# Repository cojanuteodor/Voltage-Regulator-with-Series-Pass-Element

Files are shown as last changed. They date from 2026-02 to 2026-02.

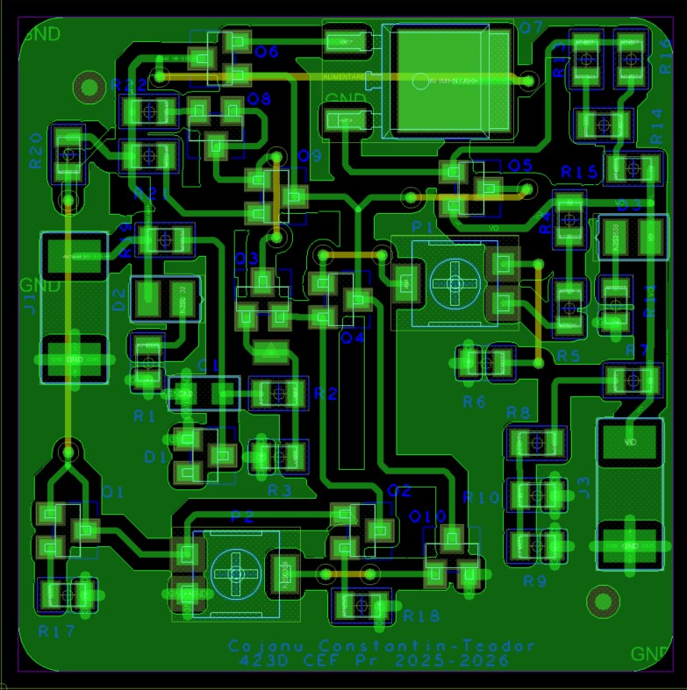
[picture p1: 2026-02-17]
Layout/Z_Z_LAYOUT.jpg

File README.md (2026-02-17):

# Voltage Regulator with Series Pass Element

## Specifications
- Adjustable output voltage: 2.5 V – 5 V  
- Input voltage range: 9 V – 10 V  
- Load resistance: 250 Ω  
- Maximum output current: 0.4 A (current limiting)  
- Thermal protection: series pass transistor limited to 100 °C  
- Thermal drift: < 2 mV/°C  
- Operating temperature range: 0 °C to 70 °C  
- Minimum open-loop voltage gain of error amplifier: ≥ 200  
- LED indicators for input and output voltage presence  

## Design Overview
The regulator is based on a linear series pass topology, where the output voltage is controlled by an error amplifier that compares a reference voltage with a feedback fraction of the output voltage. The series pass transistor operates in the linear region to regulate the output voltage under varying load and input conditions.

Main functional blocks:
- Reference voltage generator  
- Error amplifier (high open-loop gain)  
- Series pass element (BJT or MOSFET in SMD package)  
- Current limiting and thermal protection circuit  
- LED indicators for Vin and Vout  

## Implementation
- Technology: SMT & PCB  
- PCB size: 40 mm × 40 mm  
- Substrate: FR4, double-layer  
- Components: SMD 0805 passives, SMD transistors (SOT-23 / DPAK)  
- CAD Tools: OrCAD Capture & PCB Editor (Lite)  
- Simulation: PSPICE  

## Project Files
- Schematic and simulation files (PSPICE)  
- PCB layout (TOP/BOTTOM layers, solder mask, silk screen, mechanical layer)  
- Gerber files (RS-274X) and Excellon drill file  
- Bill of Materials (BOM)  
- Design documentation and calculations  

## Testing and Validation
The circuit was verified through:
- DC operating point analysis  
- Load regulation and line regulation simulations  
- Thermal behavior analysis of the series pass transistor  
- Functional testing of current limiting and thermal protection  
- Verification of output voltage range for N = 5  

## Notes
- All passive components use standard values and SMD 0805 packages.  
- Semiconductor devices are selected from standard catalogs.  
- The PCB layout follows IPC standards (IPC-2221A, IPC-7527, IPC-A-610).

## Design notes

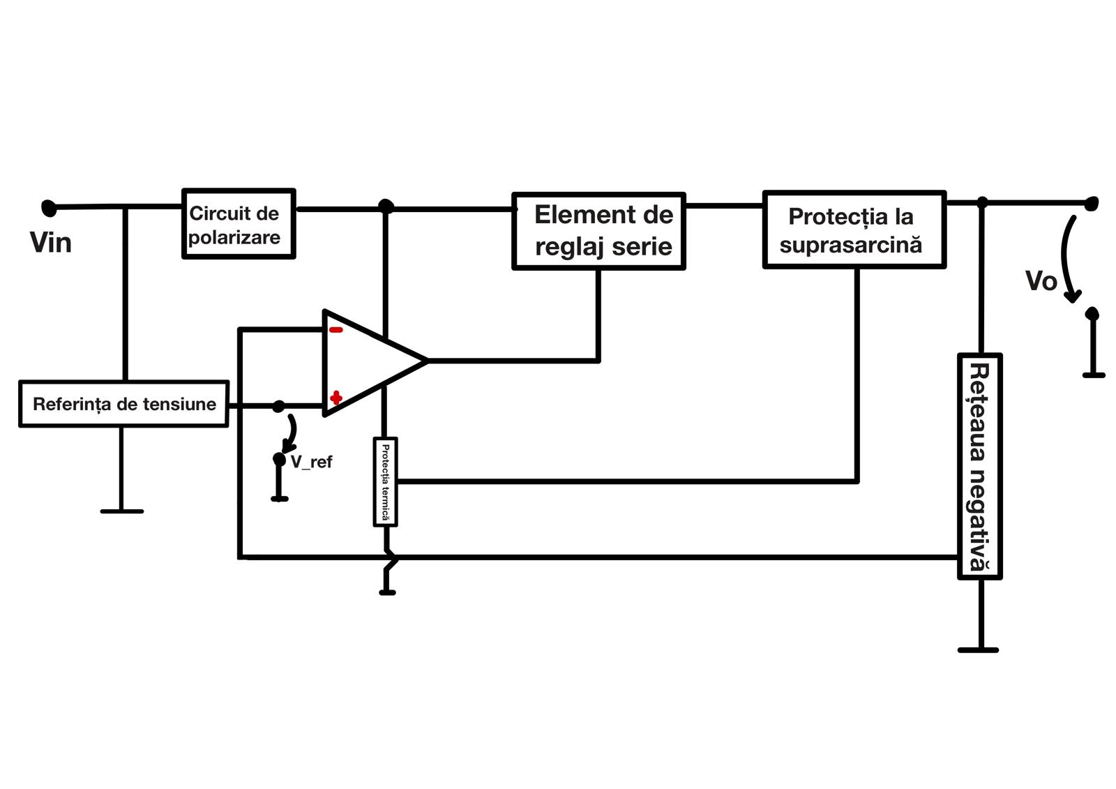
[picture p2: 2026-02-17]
schema_bloc.jpeg

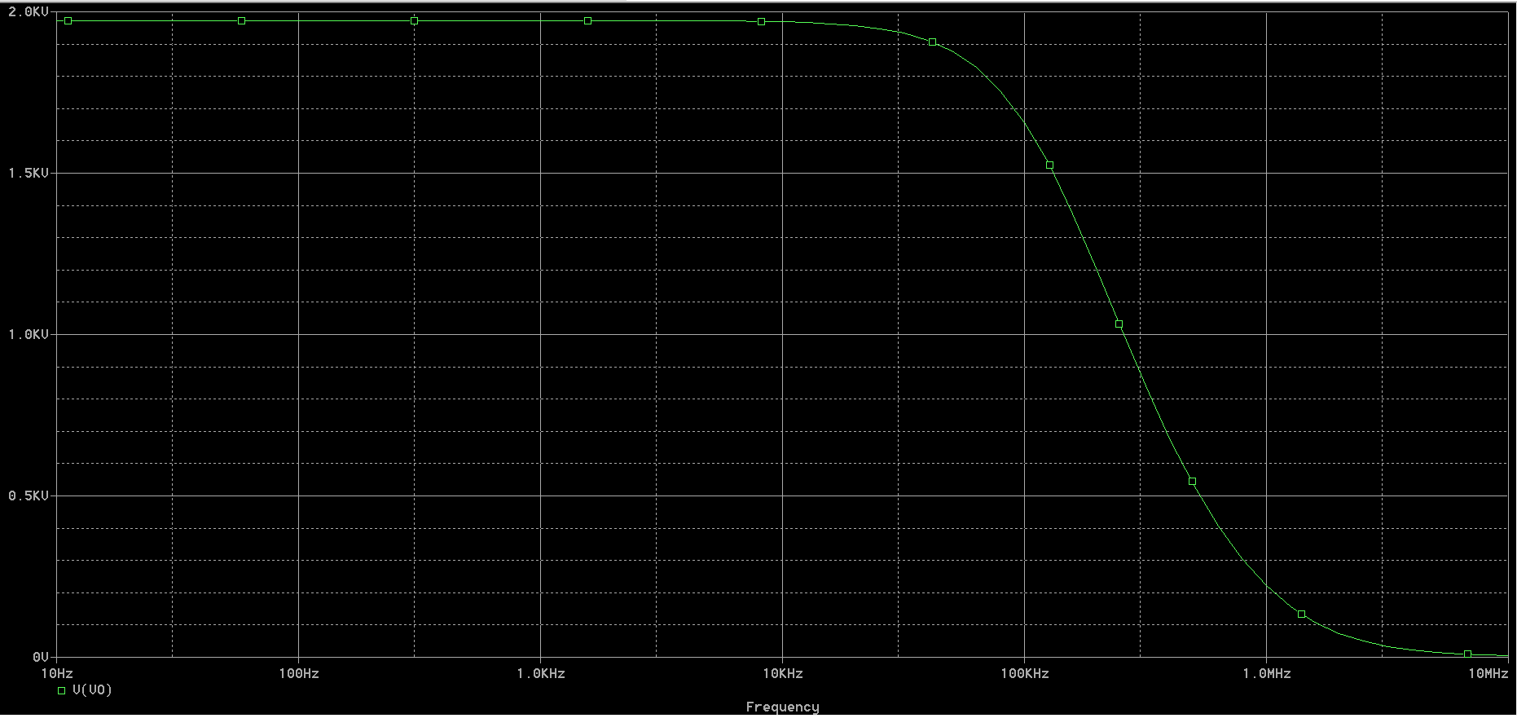
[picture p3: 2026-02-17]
Simulations/AMPLIFICARE_IN_BUCLA_DESCHISA.png

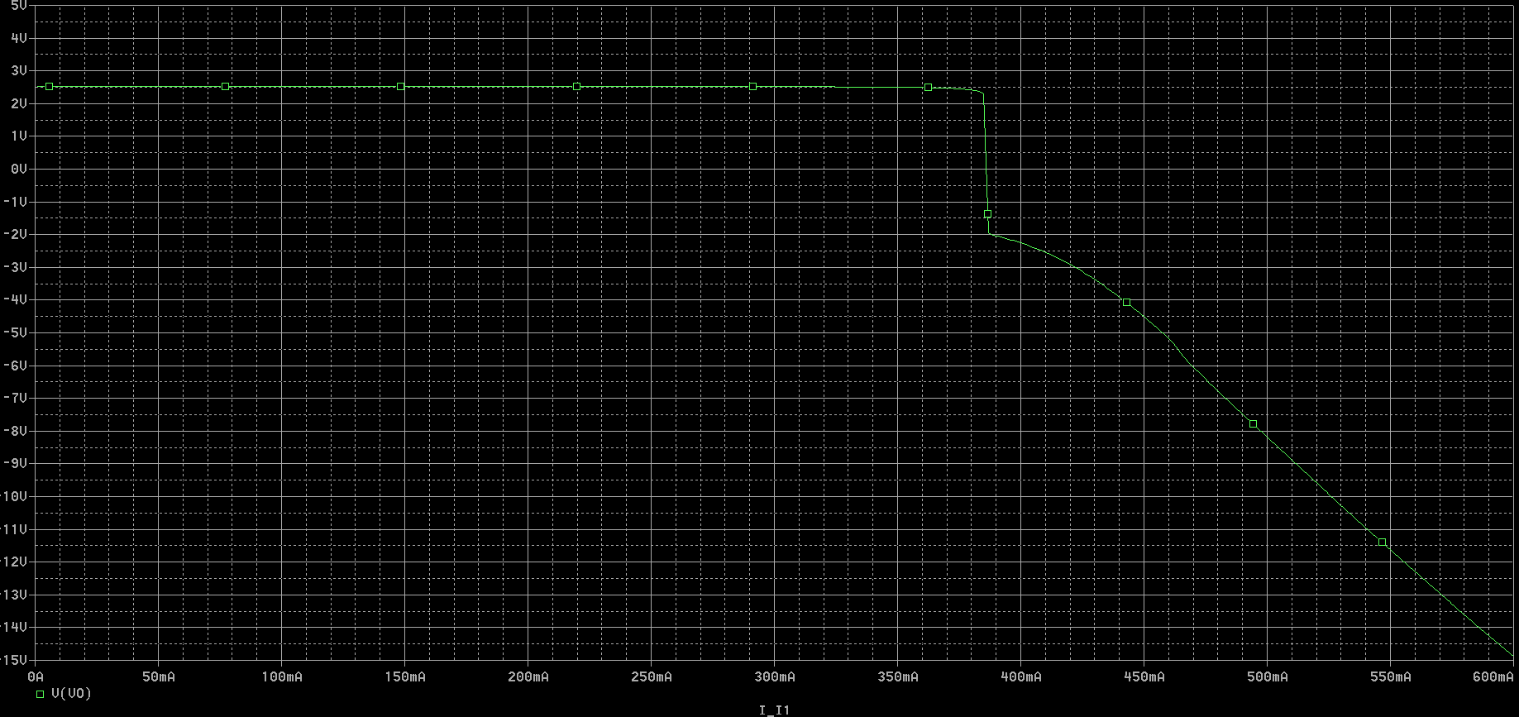
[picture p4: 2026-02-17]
Simulations/PROTECTIA_LA_SUPRASARCINA_VO_MIN.png

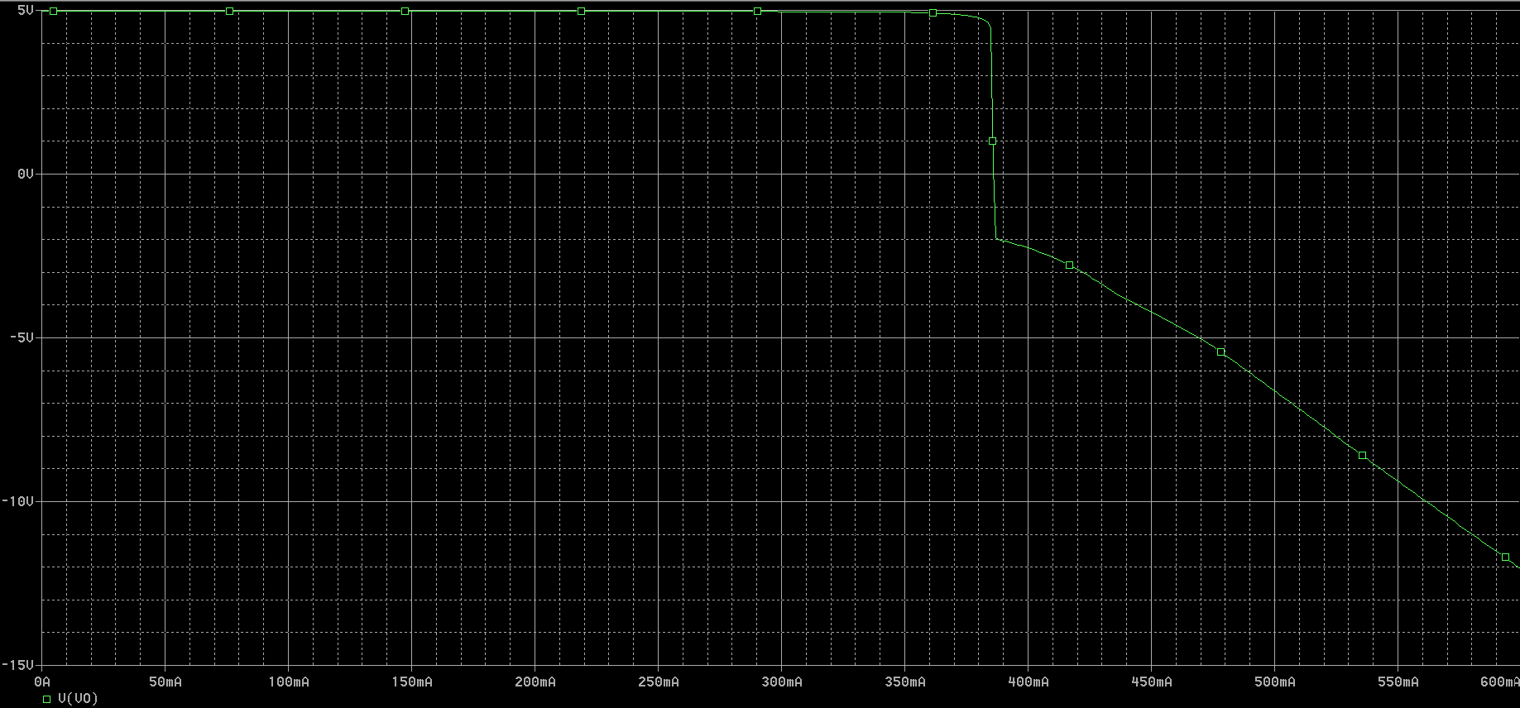
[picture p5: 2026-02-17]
Simulations/PROTECTIA_LA_SUPPRASARCINA_VO_MAX.png

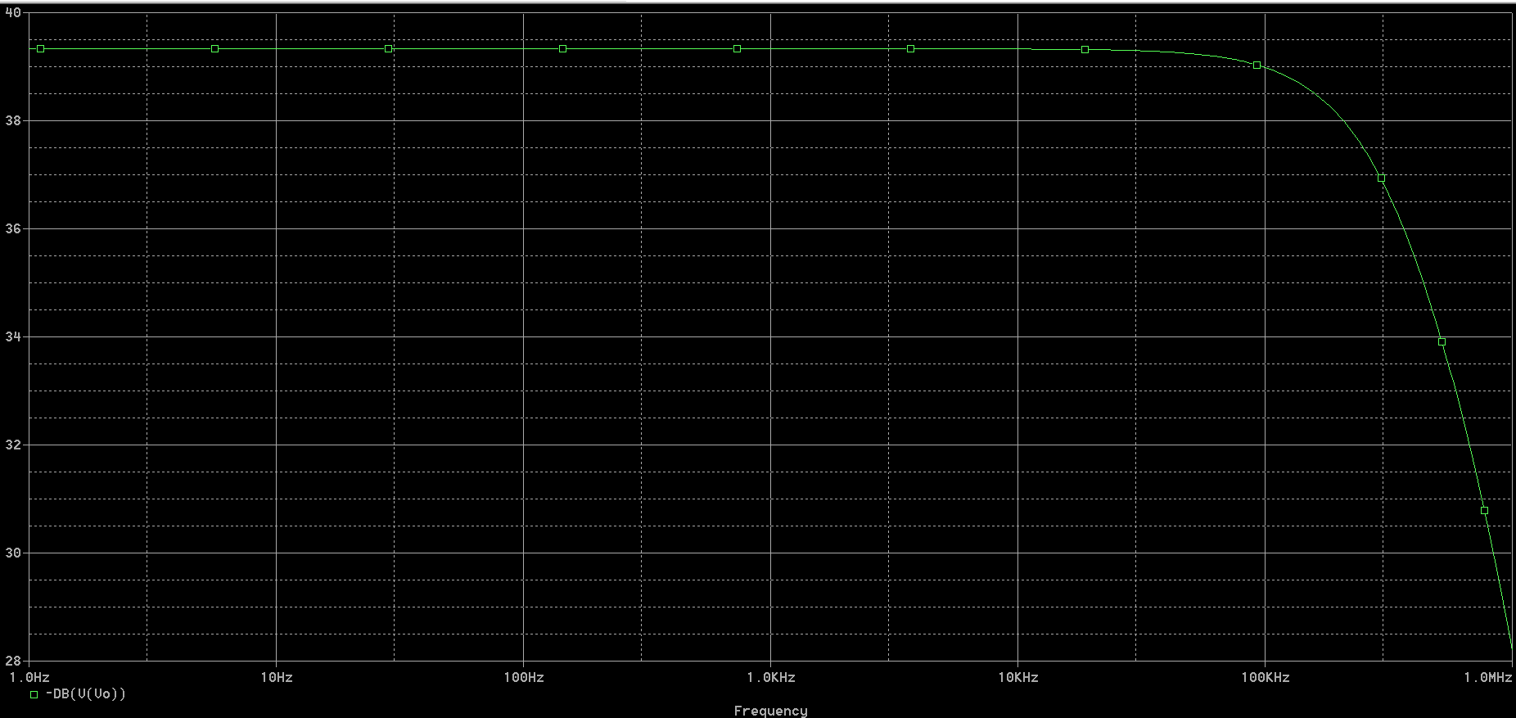
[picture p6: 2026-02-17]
Simulations/PSRR.png

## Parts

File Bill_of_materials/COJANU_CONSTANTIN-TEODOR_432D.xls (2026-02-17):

Anexa a1 - Grupa 432D - Tema 7 - Stabilizator de tensiune cu ERS
Nr. Crt. | Nume | Catalog | Cod distrib | Nume prod | Prod | Clasă | Qty fix | Qty final | Qty min | Descriere | Distribuitor | Pret (fara TVA) referinta/buc. TME România | Pret total pe reper (fara TVA) - propus
1 | 0 ohm | (LINK) (http://www.tme.eu/ro/details/smd1206-0r/rezistente-smd-1206/royal-ohm/1206s4j0000t5e/) | 1206S4J0000T5E | 1206S4J0000T5E | SR PASSIVES | rezistor | 0 |  |  | Rezistor: thick film; SMD; 1206; 0Ω; 0,25W; ±5%; -55÷125°C | TME România | 0.03841 | 0
2 | 0.47 | (LINK) (http://www.tme.eu/ro/details/smd0805-0r47/rezistente-smd-0805/royal-ohm/0805s8j047kt5e/) | SMD0805-0R47 | 0805S8J047KT5E | ROYAL OHM | rezistor | 20 |  |  | Rezistor SMD, chip, 0805, 0.47Ω, ±5%, 0.125W | TME România | 0.01454 | 0.2908
3 | 1 | (LINK) (https://www.tme.eu/ro/details/smd0805-1r/rezistente-smd-0805/royal-ohm/0805s8j010jt5e/) | SMD0805-1R-5% | 0805S8J010JT5E | ROYAL OHM | rezistor | 20 |  | 4 | Rezistor SMD, chip, 0805, 1Ω, ±5%, 0.125W | TME România | 0.01723 | 0.3446
4 | 4.7 | (LINK) (https://www.tme.eu/ro/details/smd0805-4r7/rezistente-smd-0805/royal-ohm/0805s8j047jt5e/) | SMD0805-4R7-5% | 0805S8J047JT5E | ROYAL OHM | rezistor | 10 |  |  | Rezistor SMD, chip, 0805, 4.7Ω, ±5%, 0.125W | TME România | 0.01723 | 0.1723
5 | 10 | (LINK) (https://www.tme.eu/ro/details/smd0805-10r/rezistente-smd-0805/royal-ohm/0805s8j0100t5e/) | SMD0805-10R-5% | 0805S8J0100T5E | ROYAL OHM | rezistor | 10 |  |  | Rezistor SMD, chip, 0805, 10Ω, ±5%, 0.125W | TME România | 0.01723 | 0.1723
6 | 22 | (LINK) (https://www.tme.eu/ro/details/smd0805-22r-1%25/rezistente-smd-0805/royal-ohm/0805s8f220jt5e/) | SMD0805-22R-1% | 0805S8F220JT5E | ROYAL OHM | rezistor | 20 |  |  | Rezistor SMD, chip, 0805, 22Ω, ±1%, 0.125W | TME România | 0.02127 | 0.4254
7 | 33 | (LINK) (https://www.tme.eu/ro/details/smd0805-33r/rezistente-smd-0805/royal-ohm/0805s8j0330t5e/) | SMD0805-33R-5% | 0805S8J0330T5E | ROYAL OHM | rezistor | 20 |  |  | Rezistor SMD, chip, 0805, 33Ω, ±5%, 0.125W | TME România | 0.01723 | 0.3446
8 | 51 | (LINK) (http://www.tme.eu/ro/details/rc0805jr-0751r/rezistente-smd-0805/yageo/rc0805jr-0751rl/) | SMD0805-51R-5% | 0805S8J0510T5E | ROYAL OHM | rezistor | 40 |  |  | Rezistor SMD, chip, 0805, 51Ω, ±5%, 0.125W | TME România | 0.0261 | 1.044
9 | 68 | (LINK) (http://www.tme.eu/ro/details/smd0805-68r-1%25/rezistente-smd-0805/royal-ohm/0805s8f680jt5e/) | SMD0805-68R-1% | 0805S8F680JT5E | ROYAL OHM | rezistor | 10 |  |  | Rezistor SMD, chip, 0805, 68Ω, ±1%, 0.125W | TME România | 0.04662 | 0.4662
10 | 82 | (LINK) (https://www.tme.eu/ro/details/wf08p-82r-5%25/rezistente-smd-0805/walsin/wf08p820jtl/) | SMD0805-82R-5% | WF08P820JTL | WALSIN | rezistor | 20 |  |  | Rezistor SMD, chip, 0805, 82Ω, ±5%, 0.125W | TME România | 0.0172 | 0.344
11 | 100 | (LINK) (https://www.tme.eu/ro/details/smd0805-100r/rezistente-smd-0805/royal-ohm/0805s8j0101t5e/) | SMD0805-100R-5% | 0805S8J0101T5E | ROYAL OHM | rezistor | 60 |  | 6 | Rezistor SMD, chip, 0805, 100Ω, ±5%, 0.125W | TME România | 0.01723 | 1.0338
12 | 150 | (LINK) (https://www.tme.eu/ro/details/smd0805-150r/rezistente-smd-0805/royal-ohm/0805s8j0151t5e/) | SMD0805-150R-5% | 0805S8F1500T5E | ROYAL OHM | rezistor | 30 |  |  | Rezistor SMD, chip, 0805, 150Ω, ±5%, 0.125W | TME România | 0.01723 | 0.5169
13 | 220 | (LINK) (http://www.tme.eu/ro/details/smd0805-220r-1%25/rezistente-smd-0805/royal-ohm/0805s8f2200t5e/) | SMD0805-220R-5% | 0805S8J0221T5E | ROYAL OHM | rezistor | 30 |  | 3 | Rezistor SMD, chip, 0805, 220Ω, ±5%, 0.125W | TME România | 0.02127 | 0.6381
14 | 330 | (LINK) (https://www.tme.eu/ro/details/smd0805-330r/rezistente-smd-0805/royal-ohm/0805s8j0331t5e/) | SMD0805-330R-5% | 0805S8J0331T5E | ROYAL OHM | rezistor | 30 |  |  | Rezistor SMD, chip, 0805, 330Ω, ±5%, 0.125W | TME România | 0.01723 | 0.5169
15 | 470 | (LINK) (https://www.tme.eu/ro/details/smd0805-470r/rezistente-smd-0805/royal-ohm/0805s8j0471t5e/) | SMD0805-470R-5% | 0805S8J0471T5E | ROYAL OHM | rezistor | 30 |  |  | Rezistor SMD, chip, 0805, 470Ω, ±5%, 0.125W | TME România | 0.01723 | 0.5169
16 | 510 | (LINK) (https://www.tme.eu/ro/details/smd0805-510r/rezistente-smd-0805/royal-ohm/0805s8j0511t5e/) | SMD0805-510R-5% | 0805S8J0511T5E | YAGEO | rezistor | 30 |  |  | Rezistor SMD, chip, 0805, 510Ω, ±5%, 0.125W | TME România | 0.01723 | 0.5169
17 | 680 | (LINK) (https://www.tme.eu/ro/details/smd0805-680r/rezistente-smd-0805/royal-ohm/0805s8j0681t5e/) | SMD0805-680R-5% | 0805S8J0681T5E | ROYAL OHM | rezistor | 30 |  | 1 | Rezistor SMD, chip, 0805, 680Ω, ±5%, 0.125W | TME România | 0.01723 | 0.5169
18 | 820 | (LINK) (https://www.tme.eu/ro/details/smd0805-820r/rezistente-smd-0805/royal-ohm/0805s8j0821t5e/) | SMD0805-820R-5% | 0805S8J0821T5E | ROYAL OHM | rezistor | 30 |  |  | Rezistor SMD, chip, 0805, 820Ω, ±5%, 0.125W | TME România | 0.01723 | 0.5169
19 | 910 | (LINK) (https://www.tme.eu/ro/details/rc0805jr-07910r/rezistente-smd-0805/yageo/rc0805jr-07910rl/) | SMD0805-910R-5% | RC0805JR-07910RL | YAGEO | rezistor | 40 |  |  | Rezistor SMD, chip, 0805, 910Ω, ±5%, 0.125W | TME România | 0.0261 | 1.044
20 | 1k | (LINK) (https://www.tme.eu/ro/details/smd0805-1k/rezistente-smd-0805/royal-ohm/0805s8j0102t5e/) | SMD0805-1K-5% | 0805S8J0102T5E | ROYAL OHM | rezistor | 100 |  | 2 | Rezistor SMD, chip, 0805, 1kΩ, ±5%, 0.125W | TME România | 0.01723 | 1.723
21 | 1.5k | (LINK) (https://www.tme.eu/ro/details/wf08p-1k5-5%25/rezistente-smd-0805/walsin/wf08p152jtl/) | SMD0805-1K5-5% | WF08P152JTL | WALSIN | rezistor | 40 |  |  | Rezistor SMD, chip, 0805, 1.5kΩ, ±5%, 0.125W | TME România | 0.0172 | 0.688
22 | 1.8k | (LINK) (https://www.tme.eu/ro/details/smd0805-1k8/rezistente-smd-0805/royal-ohm/0805s8j0182t5e/) | SMD0805-1K8-5% | 0805S8J0182T5E | ROYAL OHM | rezistor | 30 |  |  | Rezistor SMD, chip, 0805, 1.8kΩ, ±5%, 0.125W | TME România | 0.01723 | 0.5169
23 | 2k | (LINK) (https://www.tme.eu/ro/details/smd0805-2k/rezistente-smd-0805/royal-ohm/0805s8j0202t5e/) | SMD0805-2K-5% | 0805S8J0202T5E | ROYAL OHM | rezistor | 80 |  |  | Rezistor SMD, chip, 0805, 2kΩ, ±5%, 0.125W | TME România | 0.01723 | 1.3784
24 | 2.2k | (LINK) (https://www.tme.eu/ro/details/smd0805-2k2/rezistente-smd-0805/royal-ohm/0805s8j0222t5e/) | SMD0805-2K2-5% | 0805S8J0222T5E | ROYAL OHM | rezistor | 30 |  |  | Rezistor SMD, chip, 0805, 2.2kΩ, ±5%, 0.125W | TME România | 0.01723 | 0.5169
25 | 2.7k | (LINK) (https://www.tme.eu/ro/details/smd0805-2k7/rezistente-smd-0805/royal-ohm/0805s8j0272t5e/) | SMD0805-2K7-5% | 0805S8F2701T5E | ROYAL OHM | rezistor | 30 |  |  | Rezistor SMD, chip, 0805, 2.7kΩ, ±5%, 0.125W | TME România | 0.01723 | 0.5169
26 | 3.3k | (LINK) (https://www.tme.eu/ro/details/smd0805-3k3/rezistente-smd-0805/royal-ohm/0805s8j0332t5e/) | SMD0805-3K3-5% | 0805S8J0332T5E | ROYAL OHM | rezistor | 20 |  | 2 | Rezistor SMD, chip, 0805, 3.3kΩ, ±5%, 0.125W | TME România | 0.01723 | 0.3446
27 | 3.9k | (LINK) (https://www.tme.eu/ro/details/smd0805-3k9/rezistente-smd-0805/royal-ohm/0805s8j0392t5e/) | SMD0805-3K9-5% | 0805S8J0392T5E | ROYAL OHM | rezistor | 20 |  | 1 | Rezistor SMD, chip, 0805, 3.9kΩ, ±5%, 0.125W | TME România | 0.01723 | 0.3446
28 | 4.7k | (LINK) (https://www.tme.eu/ro/details/smd0805-4k7/rezistente-smd-0805/royal-ohm/0805s8j0472t5e/) | SMD0805-4K7-5% | 0805S8J0472T5E | ROYAL OHM | rezistor | 30 |  |  | Rezistor SMD, chip, 0805, 4.7kΩ, ±5%, 0.125W | TME România | 0.01723 | 0.5169
29 | 5.6k | (LINK) (https://www.tme.eu/ro/details/smd0805-5k6/rezistente-smd-0805/royal-ohm/0805s8j0562t5e/) | SMD0805-5K6-5% | 0805S8J0562T5E | ROYAL OHM | rezistor | 40 |  | 2 | Rezistor SMD, chip, 0805, 5.6kΩ, ±5%, 0.125W | TME România | 0.01723 | 0.6892
30 | 6.8k | (LINK) (https://www.tme.eu/ro/details/rc0805jr-076k8/rezistente-smd-0805/yageo/rc0805jr-076k8l/) | SMD0805-6K8-5% | RC0805JR-076K8L | YAGEO | rezistor | 20 |  |  | Rezistor SMD, chip, 0805, 6.8kΩ, ±5%, 0.125W | TME România | 0.0261 | 0.522
31 | 8.2k | (LINK) (https://www.tme.eu/ro/details/smd0805-8k2/rezistente-smd/royalohm/0805s8j0822t5e/) | SMD0805-8K2-5% | 0805S8J0822T5E | ROYAL OHM | rezistor | 30 |  |  | Rezistor SMD, chip, 0805, 8.2kΩ, ±5%, 0.125W | TME România | 0.01723 | 0.5169
32 | 9.1k | (LINK) (https://www.tme.eu/ro/details/smd0805-9k1/rezistente-smd-0805/royal-ohm/0805s8j0912t5e/) | SMD0805-9K1-5% | 0805S8J0912T5E | ROYAL OHM | rezistor | 20 |  |  | Rezistor SMD, chip, 0805, 9.1kΩ, ±5%, 0.125W | TME România | 0.01723 | 0.3446
33 | 10k | (LINK) (https://www.tme.eu/ro/details/smd0805-10k/rezistente-smd-0805/royal-ohm/0805s8j0103t5e/) | SMD0805-10K-5% | 0805S8J0103T5E | ROYAL OHM | rezistor | 100 |  |  | Rezistor SMD, chip, 0805, 10kΩ, ±5%, 0.125W | TME România | 0.01723 | 1.723
34 | 15k | (LINK) (https://www.tme.eu/ro/details/smd0805-15k/rezistente-smd-0805/royal-ohm/0805s8j0153t5e/) | SMD0805-15K-5% | 0805S8J0153T5E | ROYAL OHM | rezistor | 30 |  |  | Rezistor SMD, chip, 0805, 15kΩ, ±5%, 0.125W | TME România | 0.01723 | 0.5169
35 | 22k | (LINK) (https://www.tme.eu/ro/details/smd0805-22k/rezistente-smd-0805/royal-ohm/0805s8j0223t5e/) | SMD0805-22K-5% | 0805S8J0223T5E | ROYAL OHM | rezistor | 30 |  |  | Rezistor SMD, chip, 0805, 22kΩ, ±5%, 0.125W | TME România | 0.01723 | 0.5169
36 | 47k | (LINK) (http://www.tme.eu/ro/details/smd0805-47k/rezistente-smd-0805/royal-ohm/0805s8j0473t5e/) | SMD0805-47K-5% | 0805S8J0473T5E | ROYAL OHM | rezistor | 40 |  |  | Rezistor: thick film; SMD; 0805; 47kΩ; 0,125W; ±5%; -55÷125°C | TME România | 0.01723 | 0.6892
37 | 68k | (LINK) (https://www.tme.eu/ro/details/smd0805-68k/rezistente-smd-0805/royal-ohm/0805s8j0683t5e/) | SMD0805-68K-5% | 0805S8J0683T5E | ROYAL OHM | rezistor | 20 |  |  | Rezistor SMD, chip, 0805, 68kΩ, ±5%, 0.125W | TME România | 0.01723 | 0.3446
38 | 100k | (LINK) (https://www.tme.eu/ro/details/smd0805-100k/rezistente-smd-0805/royal-ohm/0805s8j0104t5e/) | SMD0805-100K-5% | 0805S8J0104T5E | ROYAL OHM | rezistor | 100 |  |  | Rezistor SMD, chip, 0805, 100kΩ, ±5%, 0.125W | TME România | 0.01723 | 1.723
39 | 150k | (LINK) (http://www.tme.eu/ro/details/smd0805-150k/rezistente-smd-0805/royal-ohm/0805s8j0154t5e/) | SMD0805-150K-5% | 0805S8J0154T5E | ROYAL OHM | rezistor | 30 |  |  | Rezistor SMD, chip, 0805, 150kΩ, ±5%, 0.125W | TME România | 0.01723 | 0.5169
40 | 180k | (LINK) (http://www.tme.eu/ro/details/smd0805-180k/rezistente-smd-0805/royal-ohm/0805s8j0184t5e/) | SMD0805-180K-5% | 0805S8J0184T5E | ROYAL OHM | rezistor | 30 |  |  | Rezistor SMD, chip, 0805, 180kΩ, ±5%, 0.125W | TME România | 0.01723 | 0.5169
41 | 220k | (LINK) (https://www.tme.eu/ro/details/smd0805-220k/rezistente-smd-0805/royal-ohm/0805s8j0224t5e/) | SMD0805-220K-5% | 0805S8J0224T5E | ROYAL OHM | rezistor | 30 |  |  | Rezistor SMD, chip, 0805, 220kΩ, ±5%, 0.125W | TME România | 0.01723 | 0.5169
42 | 330k | (LINK) (https://www.tme.eu/ro/details/smd0805-330k/rezistente-smd-0805/royal-ohm/0805s8j0334t5e/) | SMD0805-330K-5% | 0805S8J0334T5E | ROYAL OHM | rezistor | 30 |  |  | Rezistor SMD, chip, 0805, 330kΩ, ±5%, 0.125W | TME România | 0.01723 | 0.5169
43 | 390k | (LINK) (https://www.tme.eu/ro/details/smd0805-390k/rezistente-smd-0805/royal-ohm/0805s8j0394t5e/) | SMD0805-390K-5% | 0805S8J0394T5E | ROYAL OHM | rezistor | 30 |  |  | Rezistor SMD, chip, 0805, 390kΩ, ±5%, 0.125W | TME România | 0.01723 | 0.5169
44 | 510k | (LINK) (https://www.tme.eu/ro/details/smd0805-510k/rezistente-smd-0805/royal-ohm/0805s8j0514t5e/) | SMD0805-510K-5% | 0805S8J0514T5E | ROYAL OHM | rezistor | 30 |  |  | Rezistor SMD, chip, 0805, 510kΩ, ±5%, 0.125W | TME România | 0.01723 | 0.5169
45 | 1M | (LINK) (https://www.tme.eu/ro/details/crcw08051m00jntabc/rezistente-smd-0805/vishay/) | SMD0805-1M-5% | CRCW08051M00JNTABC | VISHAY | rezistor | 0 |  |  | Rezistor SMD, chip, 0805, 1MΩ, ±5%, 0.125W | TME România | 0.01151 | 0
46 | 2M | (LINK) (http://www.tme.eu/ro/details/smd0805-2m/rezistente-smd-0805/royal-ohm/0805waj-2m-t5e/) | SMD0805-2M7 5% | 0805WAJ 2M T5E | ROYAL OHM | rezistor | 0 |  |  | Rezistor SMD, chip, 0805, 2MΩ, ±1%, 0.125W | TME România | 0.01723 | 0
47 | 5,1M | (LINK) (http://www.tme.eu/ro/details/smd0805-5m1/rezistente-smd-0805/royal-ohm/0805s8j0515t5e/) | SMD0805-5M1 5% | RC0805FR-075M1 | Yageo | rezistor | 0 |  |  | Rezistor SMD, chip, 0805, 5.1MΩ, ±1%, 0.125W | TME România | 0.01723 | 0
48 | 10M | (LINK) (https://www.tme.eu/ro/details/0805s8j0106t5e/rezistente-smd-0805/royal-ohm/) | SMD0805-10M 5% | 0805S8J0106T5E | ROYAL OHM | rezistor | 0 |  |  | Rezistor SMD, chip, 0805, 10MΩ, ±5%, 0.125W | TME România | 0.01723 | 0
49 | 100ohm | (LINK) (https://www.tme.eu/ro/details/ts53yl100r/trimere-smd-cu-o-singura-tura/vishay/ts53yl101mr10/) | 1804GSMD-100R | 1804GSMD-100R | SR PASSIVES | potențiometru | 15 |  |  | Potențiome-tru liniar, simplă tură, SMD, 100Ω, ±10%, 100ppm/°C, 0.25W | TME România | 3.77 | 56.55
50 | 500ohm | (LINK) (https://www.tme.eu/ro/details/ts53yl500r/trimere-smd-cu-o-singura-tura/vishay/ts53yl501mr10/) | 1804GSMD-500R | 1804GSMD-500R | VISHAY | potențiometru | 0 |  |  | Potențiome-tru liniar, simplă tură, SMD, 500Ω, ±10%, 100ppm/°C, 0.25W | TME România | 2.19 | 0
51 | 2k | (LINK) (https://www.tme.eu/ro/details/ts53yl2k/trimere-smd-cu-o-singura-tura/vishay/ts53yl202mr10/) | TS53YL202MR10 | TS53YL202MR10 | VISHAY | potențiometru | 0 |  |  | Potențiome-tru liniar, simplă tură, SMD, 2kΩ, ±20%, 100ppm/°C, 0.25W | TME România | 2.84 | 0
52 | 5k | (LINK) (http://www.tme.eu/ro/details/3314g-1-502e/trimere-smd-cu-o-singura-tura/bourns/) | 3314G-1-502E | 3314G-1-502E | BOURNS | potențiometru | 40 |  | 2 | Potențiome-tru liniar, simplă tură, SMD, 5kΩ, ±20%, 100ppm/°C, 0.25W | TME România | 3.45 | 138
53 | 10k | (LINK) (http://www.tme.eu/ro/details/3314g-1-103e/trimere-smd-cu-o-singura-tura/bourns/) | 3314G-1-103E | 3314G-1-103E | BOURNS | potențiometru | 20 |  |  | Potențiome-tru liniar, simplă tură, SMD, 10kΩ, ±20%, 100ppm/°C, 0.25W | TME România | 3.0573 | 61.146
54 | 50k | (LINK) (http://www.tme.eu/ro/details/3314g-1-503e/trimere-smd-cu-o-singura-tura/bourns/) | 3314G-1-503E | 3314G-1-503E | BOURNS | potențiometru | 0 |  |  | Potențiome-tru liniar, simplă tură, SMD, 50kΩ, ±20%, 100ppm/°C, 0.25W | TME România | 2.84 | 0
55 | 100k | (LINK) (http://www.tme.eu/ro/details/ts53yl100k/trimere-smd-cu-o-singura-tura/vishay/ts53yl104mr10/) | TS53YL104MR10 | TS53YL104MR10 | VISHAY | potențiometru | 10 |  |  | Potențiome-tru liniar, simplă tură, SMD, 100kΩ, ±20%, 100ppm/°C, 0.25W | TME România | 2.61 | 26.1
56 | 500k | (LINK) (http://www.tme.eu/ro/details/3314g-1-504e/trimere-smd-cu-o-singura-tura/bourns/) | 3314G-1-504E | 3314G-1-504E | BOURNS | potențiometru | 0 |  |  | Potențiome-tru liniar, simplă tură, SMD, 500kΩ, ±10%, 100ppm/°C, 0.25W | TME România | 2.8802 | 0
 | TOTAL - Componente pasive (rezistoare de valori fixe şi reglabile) |  |  |  |  |  |  |  |  | FARA TVA = | 308.4514 | CU TVA= | 382.479736
57 | 4.7pF | (LINK) (http://www.tme.eu/ro/details/cc0805crnpo94r7/condensatoare-mlcc-smd-0805/yageo/cc0805crnpo9bn4r7/) | CC0805CRNPO9BN4R7 | CC0805CRNPO9BN4R7 | YAGEO | condensator | 20 |  |  | ceramic; MLCC; 4,7pF; 50V; C0G; ±0,25pF; SMD; 0805 | TME România | 0.16643 | 3.3286
58 | 10pF | (LINK) (http://www.tme.eu/ro/details/cc0805jrnpo9100/condensatoare-mlcc-smd-0805/yageo/cc0805jrnpo9bn100/) | CC0805JRNPO9BN100 | CC0805JRNPO9BN100 | YAGEO | condensator | 20 |  |  | ceramic; MLCC; 10pF; 50V; C0G; ±5%; SMD; 0805 | TME România | 0.1649 | 3.298
59 | 47pF | (LINK) (http://www.tme.eu/ro/details/cl21c470jbannnc/condensatoare-mlcc-smd-0805/samsung/) | CL21C470JBANNNC | CL21C470JBANNNC | SAMSUNG | condensator | 20 |  |  | Condensator: ceramic; MLCC; 47pF; 50V; C0G; ±5%; SMD; 0805; -55÷125°C | TME România | 0.11097 | 2.2194
60 | 100pF | (LINK) (http://www.tme.eu/ro/details/cl21c101jbannnc/condensatoare-mlcc-smd-0805/samsung/) | CL21C101JBANNNC | CL21C101JBANNNC | SAMSUNG | condensator | 20 |  |  | Condensator: ceramic; MLCC; 100pF; 50V; C0G; ±5%; SMD; 0805 | TME România | 0.05427 | 1.0854
61 | 470pF | (LINK) (https://www.tme.eu/ro/details/c0805c471k5rac/condensatoare-mlcc-smd/kemet/c0805c471k5ractu/) | C0805C471K5RACTU | C0805C471K5RACTU | KEMET | condensator | 20 |  |  | Condensator: ceramic; MLCC; 470pF; 50V; X7R; ±10%; SMD; 0805 | TME România | 0.12123 | 2.4246
62 | 1nF | (LINK) (https://www.tme.eu/ro/details/cl21b102kbannnc/condensatoare-mlcc-smd/samsung/) | CL21B102KBANNNC | CL21B102KBANNNC | SAMSUNG | condensator | 0 |  |  | Condensator MLCC, SMD, 0805, 1nF, ±5%, 50V, C0G | TME România | 0.06487 | 0
63 | 2.2nF | (LINK) (https://www.tme.eu/ro/details/cl21b222jbannnc/condensatoare-mlcc-smd-0805/samsung/) | CL21B222JBANNNC | CL21B222JBANNNC | SAMSUNG | condensator | 0 |  |  | Condensator: ceramic; MLCC; 2,2nF; 50V; X7R; ±10%; SMD; 0805 | TME România | 0.1485 | 0
64 | 4.7nF | (LINK) (https://www.tme.eu/ro/details/cl21b472kbannnc/condensatoare-mlcc-smd-0805/samsung/) | CL21B472KBANNNC | CL21B472KBANNNC | SAMSUNG | condensator | 0 |  |  | Condensator MLCC, SMD, 0805, 4.7nF, ±5%, 50V, X7R | TME România | 0.08943 | 0
65 | 5.6nF | (LINK) (https://www.tme.eu/ro/details/cl21b562kbannnc/condensatoare-mlcc-smd-0805/samsung/) | CL21B562KBANNNC | CL21B562KBANNNC | SAMSUNG | condensator | 0 |  |  | Condensator MLCC, SMD, 0805, 5.6nF, ±5%, 50V, X7R | TME România | 0.04517 | 0
66 | 10nF | (LINK) (https://www.tme.eu/ro/details/cl21b103kbannnd/condensatoare-mlcc-smd-0805/samsung/) | CL21B103KBANNND | CL21B103KBANNND | SAMSUNG | condensator | 40 |  | 1 | Condensator MLCC, SMD, 0805, 10nF, ±5%, 50V, X7R | TME România | 0.06093 | 2.4372
67 | 22nF | (LINK) (http://www.tme.eu/ro/details/cl21b223kcfnnne/condensatoare-mlcc-smd-0805/samsung/) | CL21B223KBANNNC | CL21B223KBANNNC | SAMSUNG | condensator | 0 |  |  | Condensator: ceramic; MLCC; 22nF; 100V; X7R; ±10%; SMD; 0805 | TME România | 0.13823 | 0
68 | 33nF | (LINK) (https://www.tme.eu/ro/details/vj0805y333kxacw1bc/condensatoare-mlcc-smd-0805/vishay/) | VJ0805Y333KXACW1BC | VJ0805Y333KXACW1BC | VISHAY | condensator | 0 |  |  | Condensator: ceramic; MLCC; 33nF; 50V; X7R; ±10%; SMD; 0805 | TME România | 0.05417 | 0
69 | 100nF | (LINK) (https://www.tme.eu/ro/details/cl21b104kbcnnnc/condensatoare-mlcc-smd/samsung/) | CL21B104KBCNNNC | CL21B104KBCNNNC | SAMSUNG | condensator | 40 |  |  | ceramic; MLCC; 100nF; 50V; X7R; ±10%; SMD; 0805 | TME România | 0.3759 | 15.036
70 | 220nF | (LINK) (http://www.tme.eu/ro/details/cl21b224kafnnne/condensatoare-mlcc-smd-0805/samsung/) | CL21B224KAFNNNE | CL21B224KAFNNNE | SAMSUNG | condensator | 0 |  |  | Condensator: ceramic; MLCC; 220nF; 25V; X7R; ±10%; SMD; 0805 | TME România | 0.10247 | 0
71 | 330nF | (LINK) (https://www.tme.eu/ro/details/grm219r71h334ka88d/condensatoare-mlcc-smd-0805/murata/) | GRM219R71H334KA88D | GRM219R71H334KA88D | MURATA | condensator | 0 |  |  | Condensator: ceramic; MLCC; 330nF; 50V; X7R; ±10%; SMD; 0805 | TME România | 0.5972 | 0
72 | 470nF | (LINK) (https://www.tme.eu/ro/details/cc0805mry5v8474/condensatoare-mlcc-smd-0805/yageo/cc0805mry5v8bb474/) | CC0805MRY5V8474 | CC0805MRY5V8BB474 | YAGEO | condensator | 0 |  |  | Condensator: ceramic; MLCC; 470nF; 50V; Y5V; -20÷+80%; SMD; 0805 | TME România | 0.0758 | 0
73 | 1uF | (LINK) (https://www.tme.eu/ro/details/cl21b105kbfnnng/condensatoare-mlcc-smd-0805/samsung/) | CL21B105KBFNNNG | CL21B105KBFNNNG | SAMSUNG | condensator | 20 |  |  | Condensator: ceramic; MLCC; 1uF; 50V; X7R; ±20%; SMD; 0805 | TME România | 0.25253 | 5.0506
74 | 2.2uF | (LINK) (https://www.tme.eu/ro/details/grm21br61h225ka73l/condensatoare-mlcc-smd-0805/murata/) | GRM21BR61H225KA73L | GRM21BR61H225KA73L | MURATA | condensator | 20 |  |  | Condensator: ceramic; MLCC; 2,2uF; 25V; X5R; ±10%; SMD; 0805 | TME România | 0.4486 | 8.972
75 | 4.7uF | (LINK) (https://www.tme.eu/ro/details/cl21a475kaqnnng/condensatoare-mlcc-smd-0805/samsung/) | CL21A475KAQNNNG | CL21A475KAQNNNG | SAMSUNG | condensator | 20 |  |  | ceramic; MLCC; 4,7uF; 25V; X5R; ±10%; SMD; 0805 | TME România | 0.25373 | 5.0746
76 | 10uF | (LINK) (https://www.tme.eu/ro/details/eee1ha100sp/condensatoare-electrolitice-smd/panasonic/) | EEE1HA100SP | EEE1HA100SP | PANASONIC | condensator | 16 |  |  | Condensator: electrolitic; SMD; 10uF; 50V | TME România | 0.2284 | 3.6544
 | TOTAL - Componente pasive (condensatoare) |  |  |  |  |  |  |  |  | FARA TVA = | 52.5808 | CU TVA= | 65.200192
77 | 4148 | (LINK) (http://www.tme.eu/ro/details/1n4148-0805/diode-universale-smd/dc-components/cd4148ws0805c/) | 1N4148-0805 | CD4148WS(0805C) | DC Components | diodă pn | 40 |  |  | Diodă comutație, SMD, 0805, 300mA, 100V | TME România | 0.04555 | 1.822
78 | LED | (LINK) (https://www.tme.eu/ro/details/of-smd2012b/diode-led-smd-colorate/optoflash/) | OF-SMD2012B | OF-SMD2012B | OPTOFLASH | LED | 15 |  | 2 | LED albastru, SMD, 0805, 150-200mcd, 476nm, 120° | TME România | 0.1264 | 1.896
79 | 2.7V | (LINK) (https://www.tme.eu/ro/details/bzx84-c2v7.215/diode-zener-smd/nexperia/bzx84-c2v7-215/) | BZX84C2V7 | BZX84-C2V7LT1G | ON Semiconductor | diodă Zener | 5 |  | 1 | Diodă Zener, SMD, SOT23, 2,7V, ±5%, 0.25W | TME România | 0.05732 | 0.2866
80 | 5.1V | (LINK) (https://www.tme.eu/ro/details/bzx84-c5v1.215/diode-zener-smd/nexperia/) | BZX84C5V1 | BZX84-C5V1 | NEXPERIA | diodă Zener | 10 |  |  | Diodă Zener, SMD, SOT23, 5,1V, ±5%, 0.3W | TME România | 0.06245 | 0.6245
81 | 5.6V | (LINK) (https://www.tme.eu/ro/details/bzx84b5v6-dio/diode-zener-smd/diotec-semiconductor/bzx84b5v6/) | BZX84B5V6 | BZX84B5V6 | DIOTEC SEMICONDUCTOR | diodă Zener | 10 |  |  | Diodă Zener, SMD, SOT23, 5,6V, ±5%, 0.3W | TME România | 0.0839 | 0.839
82 | 6.2V | (LINK) (https://www.tme.eu/ro/details/bzx84-c6v2.215/diode-zener-smd/nexperia/) | BZX84C6V2 | BZX84-C6V2 | NEXPERIA | diodă Zener | 5 |  |  | Diodă Zener, SMD, SOT23, 6.2V, ±5%, 0.3W | TME România | 0.06618 | 0.3309
83 | 6.8V | (LINK) (https://www.tme.eu/ro/details/bzx84-c6v8.215/diode-zener-smd/nexperia/) | BZX84C6V8 | BZX84-C6V8 | NEXPERIA | diodă Zener | 0 |  |  | Diodă Zener, SMD, SOT23, 6.8V, ±5%, 0.3W | TME România | 0.05686 | 0
84 | 8.2V | (LINK) (https://www.tme.eu/ro/details/bzx84-c8v2.215/diode-zener-smd/nexperia/) | BZX84C8V2 | BZX84-C8V2 | NEXPERIA | diodă Zener | 5 |  |  | Diodă Zener, SMD, SOT23, 8.2V, ±5%, 0.3W | TME România | 0.05686 | 0.2843
85 | 10V | (LINK) (https://www.tme.eu/ro/details/bzx84-c10.215/diode-zener-smd/nexperia/) | BZX84C10 | BZX84-C10 | NEXPERIA | diodă Zener | 5 |  |  | Diodă Zener, SMD, SOT23, 10V, ±5%, 0.3W | TME România | 0.05686 | 0.2843
86 | PNP | (LINK) (http://www.tme.eu/ro/details/bc856b-dio/tranzistori-smd-pnp/diotec-semiconductor/bc856b/) | BC856B | BC856B | DIOTEC | tranzistor bipolar | 80 |  | 2 | Tranzistor bipolar PNP, SMD, SOT23, 80V, 100mA | TME România | 0.04055 | 3.244
87 | NPN | (LINK) (https://www.tme.eu/ro/details/bc846b-dio/tranzistori-smd-npn/diotec-semiconductor/bc846b/) | BC846B | BC846B | DIOTEC | tranzistor bipolar | 80 |  | 7 | Tranzistor bipolar NPN, SMD, SOT23, 65V, 100mA | TME România | 0.03379 | 2.7032
89 | N-JFET | (LINK) (http://www.tme.eu/ro/details/mmbfj309lt1g/tranzistori-canal-n-smd/on-semiconductor/) | MMBFJ309LT1G | MMBFJ309LT1G | ON Semiconductor | tranzistor NJFET | 40 |  |  | Tranzistor N-JFET, SMD, SOT23, 25V, 30mA | TME România | 0.8063 | 32.252
90 | P-JFET | (LINK) (http://www.tme.eu/ro/details/mmbfj177lt1g/tranzistori-canal-p-smd/on-semiconductor/) | MMBFJ177LT1G | MMBFJ177LT1G | ON Semiconductor | tranzistor PJFET | 15 |  |  | Tranzistor P-JFET, SMD, SOT23, 30V, 20mA | TME România | 0.8808 | 13.212
91 | NPN | (LINK) (http://www.tme.eu/ro/details/bc817-25-dio/tranzistori-smd-npn/diotec-semiconductor/bc817-25/) | BC817-25-DIO | BC817-25-DIO | NXP | tranzistor bipolar | 10 |  |  | Tranzistor bipolar NPN, SMD, SOT23, 45V, 800mA | TME România | 0.0494 | 0.494
93 | PNP | (LINK) (http://www.tme.eu/ro/details/bc807-25-dio/tranzistori-smd-pnp/diotec-semiconductor/bc807-25/) | BC807-25-DIO | BC807-25-DIO | NXP | tranzistor bipolar | 10 |  |  | Tranzistor bipolar PNP, SMD, SOT23, 45V, 800mA | TME România | 0.05406 | 0.5406
94 | NPN | (LINK) (http://www.tme.eu/ro/details/mjd31cg/tranzistori-smd-npn/on-semiconductor/) | MJD31CG | MJD31CG | ON Semiconductor | tranzistor bipolar | 20 |  | 1 | Tranzistor bipolar NPN, SMD, DPACK, 100V, 3A, 15W | TME România | 0.7037 | 14.074
96 | PNP | (LINK) (http://www.tme.eu/ro/details/mjd32cg/tranzistori-smd-pnp/on-semiconductor/) | MJD32CG | MJD32CG | ON Semiconductor | tranzistor bipolar | 20 |  |  | Tranzistor bipolar PNP, SMD, DPACK, 100V, 3A, 15W | TME România | 0.783 | 15.66
97 | Nmos | (LINK) (https://www.tme.eu/ro/details/irfr120ntrpbf/tranzistori-canal-n-smd/infineon-technologies/) | IRFR120NTRPBF | IRFR120NTRPBF | Infineon | tranzistor NMOS | 10 |  |  | Tranzistor N-MOSFET, SMD, DPAK, 100V, 9.1A, 20V, 39W | TME România | 1.03 | 10.3
 | TOTAL - Componente semiconductoare (tranzistoare bipolare şi cu efect de câmp, diode, LED, etc.) |  |  |  |  |  |  |  |  | FARA TVA = | 126.1474 | CU TVA= | 156.422776
98 | Conn2p | (LINK) (http://www.tme.eu/ro/details/zl301-40p/pini-cu-benzi-si-soclu/ninigi/) | ZL301-40P | ZL301-40P | NINIGI | Sir pini, pas 2,54mm, SMD | 0 |  |  | Sir pini, pas 2,54mm, SMD, tip tata, bareta de 40 pini | TME România | 2.3027 | 0
99 | FUSE | (LINK) (http://www.tme.eu/ro/details/3413.0116.11/sigurante-smd-1206-ultrarapide/schurter/) | 3413.0116.11 | 3413.0116.11 | SCHURTER | sigu-ranță | 0 |  |  | Siguranță sticlă, SMD, 1206, 1.25A, 48mΩ | TME România | 0 | 0
 | Total - Conectică, sigurante fuzibile, etc. |  |  |  |  |  |  |  |  | FARA TVA = | 0 | CU TVA= | 0
 | Total general |  |  |  |  |  |  |  |  | FARA TVA = | 487.1796 | CU TVA= | 579.743724

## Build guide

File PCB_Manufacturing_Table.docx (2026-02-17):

General info document for PCB manufacturing
No. | Item Name | File Name | | | | | | Info / Remarks / Notes
| BOARD
1 | Board Name / Number | ZSTABILIZATOR_FINAL.brd | | | | | | -
2 | Revision Date | 14 December 2025 | | | | | | -
3 | Board Size | 40 x 40 mm² | | | | | | -
4 | Board Quantity | 1 | | | | | | -
5 | Material / Dielectric Type | FR4 | | | | | | -
6 | Board Thickness | 1.6 mm | | | | | | -
7 | Copper Thickness | 18 μm | | | | | | -
| LAYERS
8 | Number of Electrical Layers | 2 | | | | | | -
9 | Copper Layer TOP | TOP.art | | | | | | -
10 | Copper Layer BOTTOM | BOT.art | | | | | | -
11 | Copper GND Plane | Included in TOP.art | | | | | | -
12 | Copper PWR Plane | - | | | | | | -
13 | Copper INNER 1 | - | | | | | | -
14 | Copper INNER 2 | - | | | | | | -
15 | Solder Mask TOP | SMTOP.art | | | | | | -
16 | Solder Mask BOTTOM | SMBOT.art | | | | | | -
17 | Solder Paste TOP | SPTOP.art | | | | | | -
18 | Solder Paste BOTTOM | - | | | | | | -
19 | Peelable Mask TOP | - | | | | | | -
20 | Peelable Mask BOTTOM | - | | | | | | -
21 | Silk Screen TOP | SSTOP.art | | | | | | -
22 | Silk Screen BOTTOM | - | | | | | | -
23 | Board Outline | BO.art | | | | | | -
24 | Fabrication Drawing | FAB.art | | | | | | -
| MILLING & DRILLING
25 | Mill Drawing | - | | | | | | -
26 | Drill Drawing | Included in FAB.art | | | | | | -
27 | N.C. Drill (for both PH & NPH) | DRILL.drl | | | | | | -
28 | N.C. Drill / Plated Holes (PH) | 14 | | | | | | -
29 | N.C. Drill / Non-Plated Holes (PH) | - | | | | | | -
| FINISHING
30 | Panelisation | - | | | | | | -
31 | Electrical Test | - | | | | | | -
32 | Copper Finishing | x | HASL | | OSP | | | ENIG
33 | Board Outline Machining | | Routing | | Milling | | x | V-Cutting
34 | Final remarks | - | | | | -

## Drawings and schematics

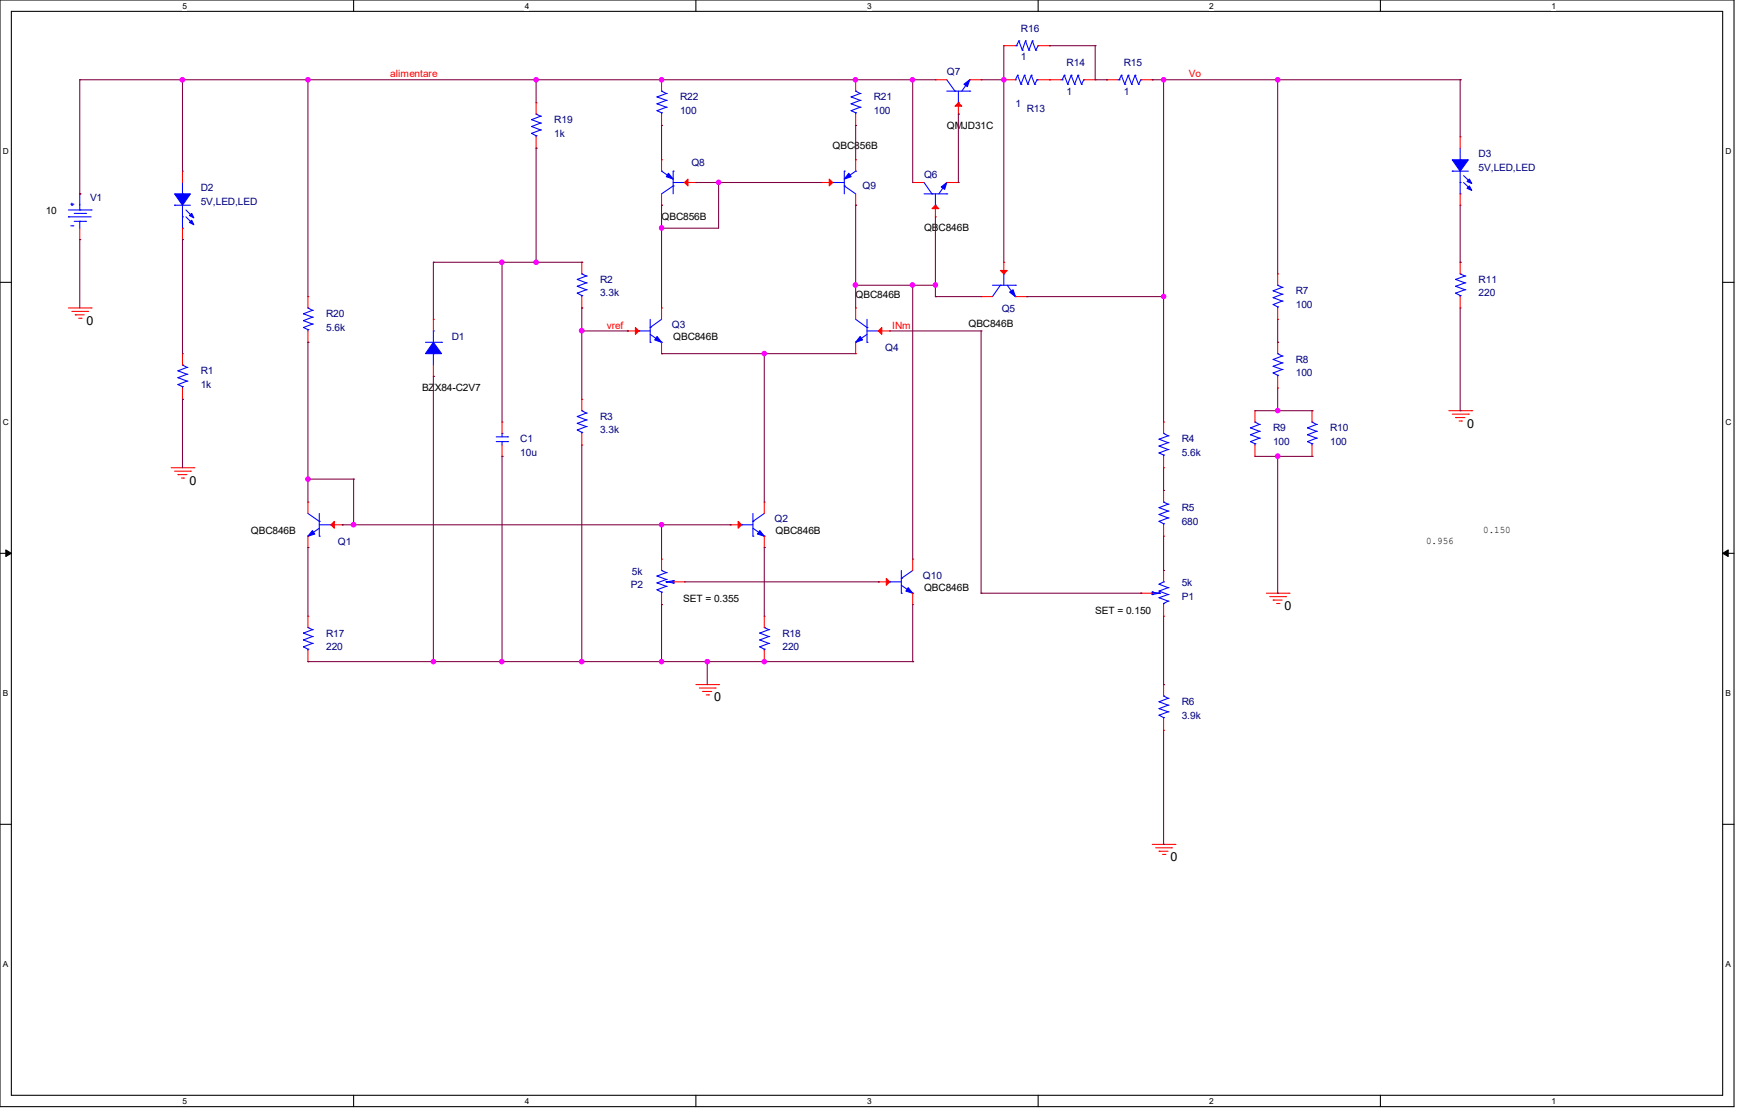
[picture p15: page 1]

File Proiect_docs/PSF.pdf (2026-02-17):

Calculate | punctulni static | de | functionate

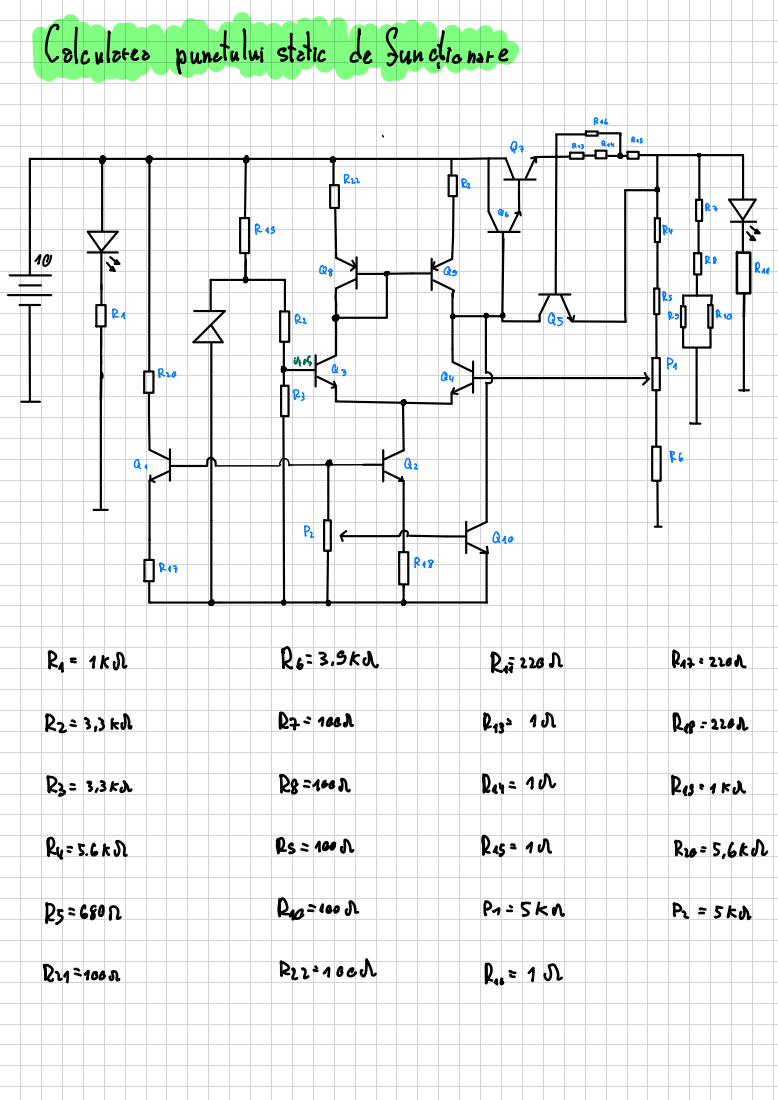
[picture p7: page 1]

& ↳ + | Qu-etaj | diferential Vinm =

# Vinp

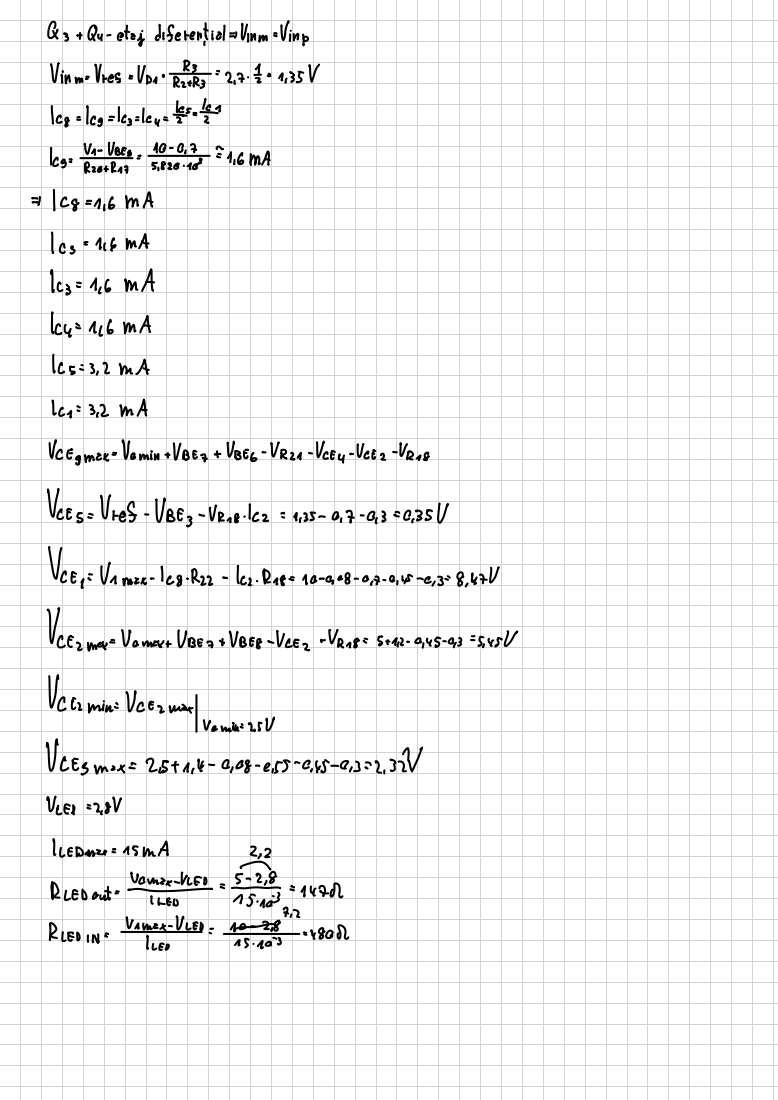
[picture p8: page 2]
Vinm= Vref; =Van R; \eg = 1cs = 1cuに; VUBEs1-EG ATA; InA; lcs; Ves = Vref-VBEy-VR18 /2; VCte = Unmax-1cg .; Res =; VCEnmer=; Vomer+ UBEz +; VBEO-VCEz; VaEz min:; VCEn max; Vomin: 2.5V; VCEsmax =; VCED; I LEDanze = 15 MA; RLEDout; Vemzx-ULED :; RLEDIN :; ILER; res

VCEgmax = Vamin +VBEz + VBEg-Vra1-Vcey-Vcez-VRes

# ↑uteri

# per resistente

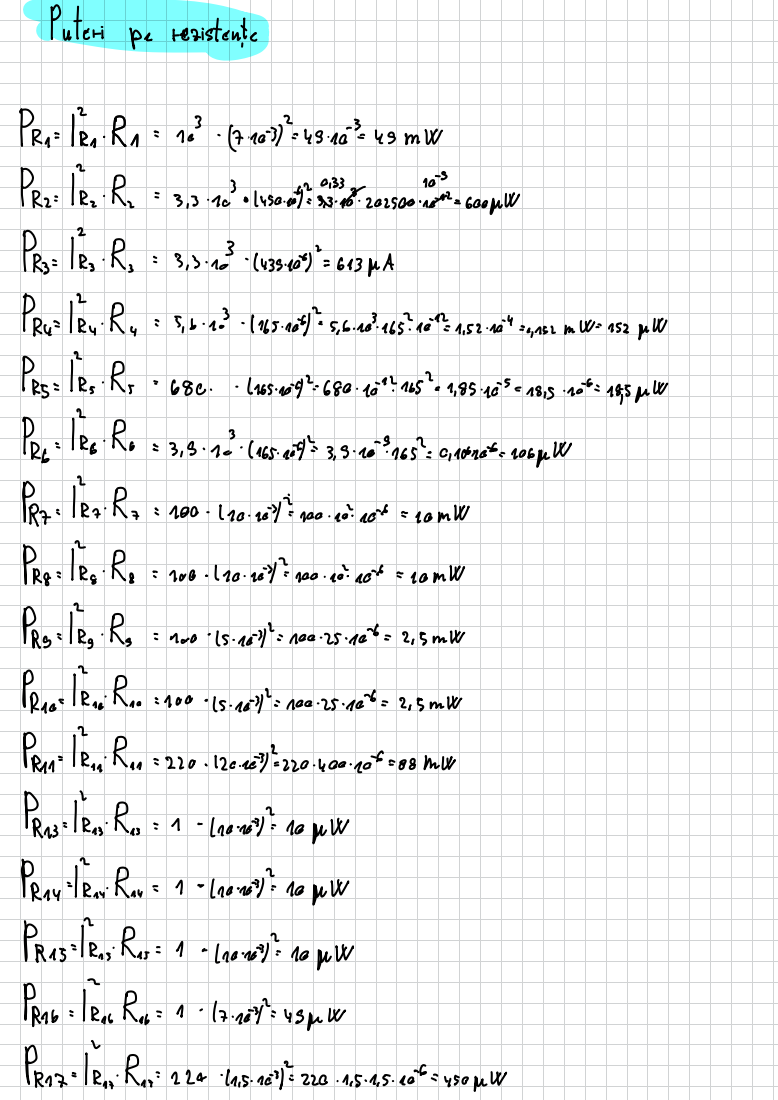
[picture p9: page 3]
PRi :; NrRRy; 703 Fre⁾'; usre” と smw; IRgR .; 103 lusaros? 33, 3 -ze'; isco-ne: Gce”; µit; 關闆虽 ∵∴ 器; ! "3snc∞; ini; nTzpt; Prs =; 闆器器““台”“; Pro :; Ers .; Prg :; Erg .; Pro=Rec Rea; PRsn =Ri Res; PRes : IRis .; Res; Leoay; /Res Res =; Spek; IRn Rez :; 450 pew

PR18 :

# ERo Rio = 220 ·

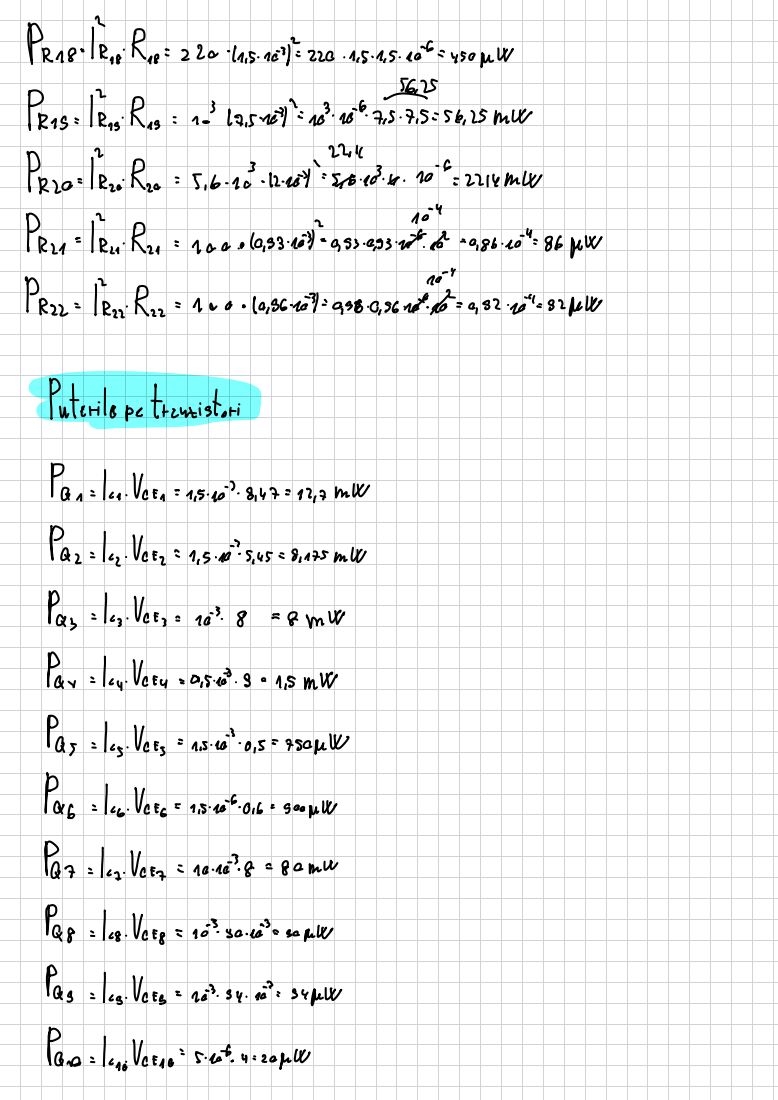
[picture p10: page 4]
peW; PRrs :; IRg Ris; srey^; sey; nny, "; sod; hey aupeme; ynas"n; Puterile petranzistori; Pan = (.; Vozn; Paz = (.; Vozz =; Pas; Very =; Pay; Vezy; Paj; Verz; +opk; Vere =; scomN; Paz; Varz; somu; Pao; Varg =; som; Vais =; sypert; Pano : Ino Vazeo"; zopk

"'sa,esh:de foiaptand asied "

Putetile | pe diode
Pe = | VD . | (pe = | 2, | 7 | · | =,

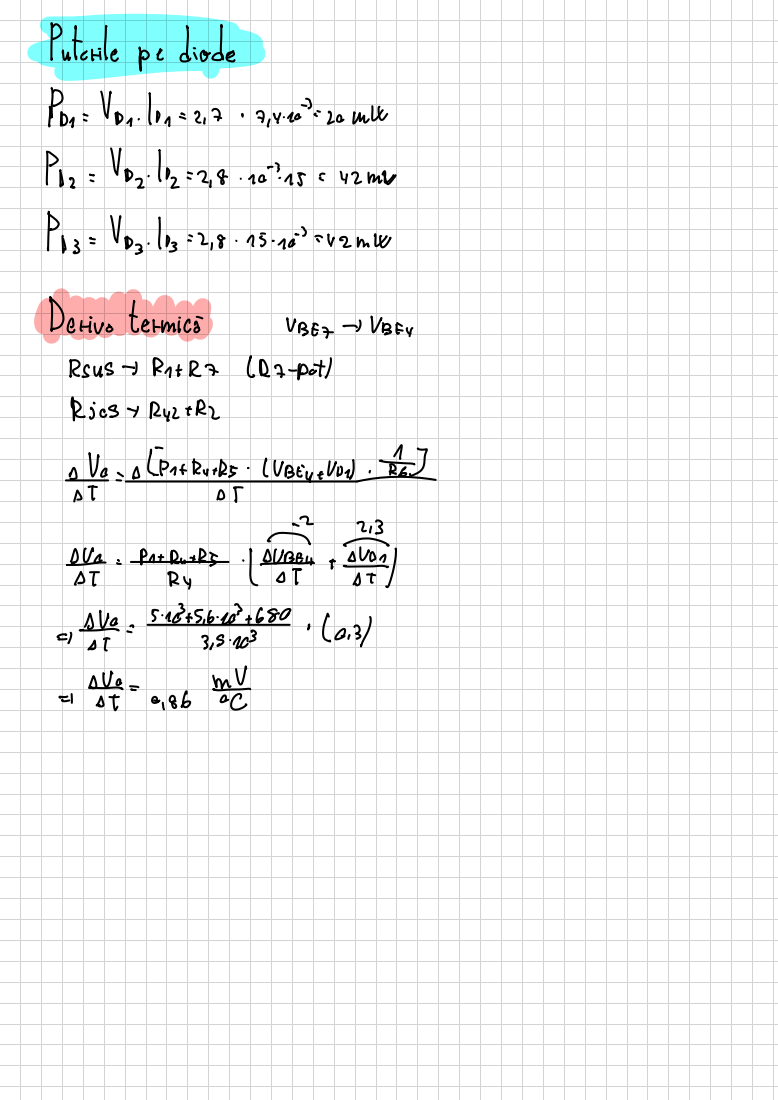
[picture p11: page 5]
yeat:; 20 mult; PHz; 2 . liz =2 ,8; VDy .; les = 2, 8; Deriva; termica; VBE7⁻VBEY; Rsus+; PutRA; (R7-pot; Rics; Ryz + R2; (Ubeytred

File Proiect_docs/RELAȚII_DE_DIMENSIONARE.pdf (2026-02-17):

Relati | de | dimensionate
1.Referinta | de tensione

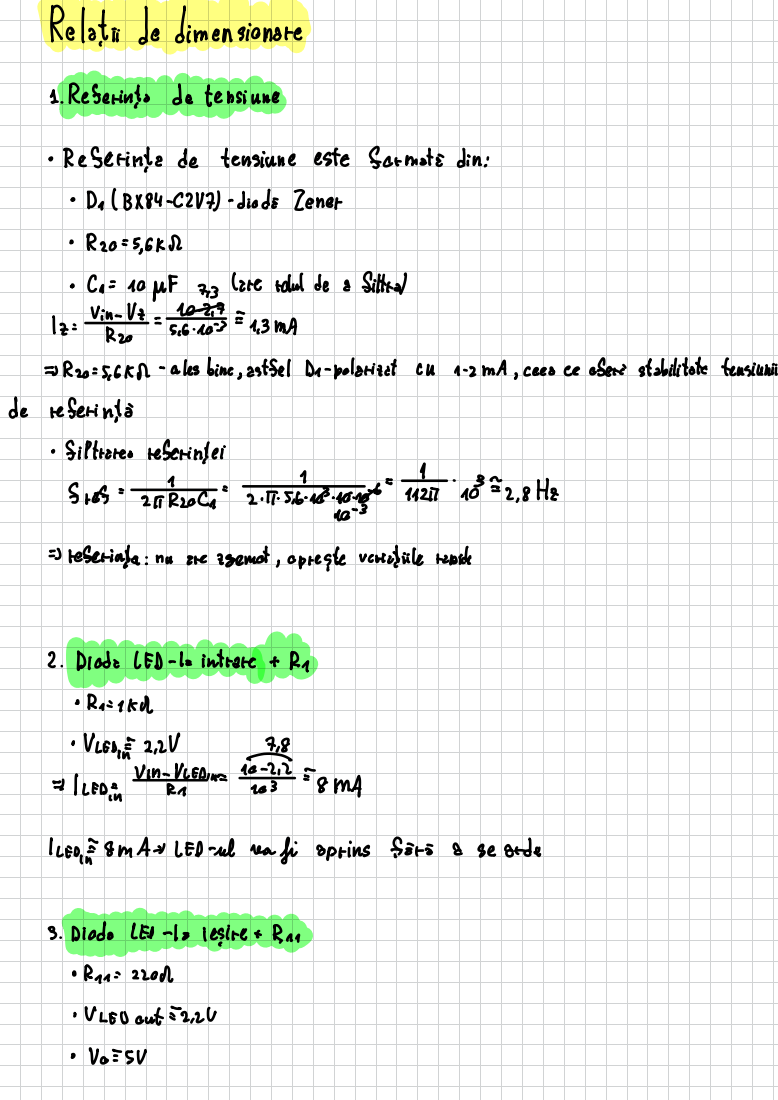
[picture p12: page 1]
Referita; tensinne; este; formati dini; diode; Zener; puf; late; toul; filtral; Vint 5c6 .; atfel; Di-polarizat; ceca; oferi; stabilitate; tensionic; referinià; filtaztea; referingei; ziRlod"; ntber²,H; referinge : nu; zgemet , opteste; vericle +epide; 2. Dioda; (E)-12 intrate + R1; VLEDir 2,2V; VIN-VLEDine ILED뮤; nezie⁻ ,δ; ILEDSMALED-ul; vafi; aprins; fitz; a searde; Diode; LED-la ieSite +; Ree; Bre =; zzoch; · VLED out2,

6 km-ales bine ,

Vo-ULEDou | 220 | 1 mA
)) = | な 6

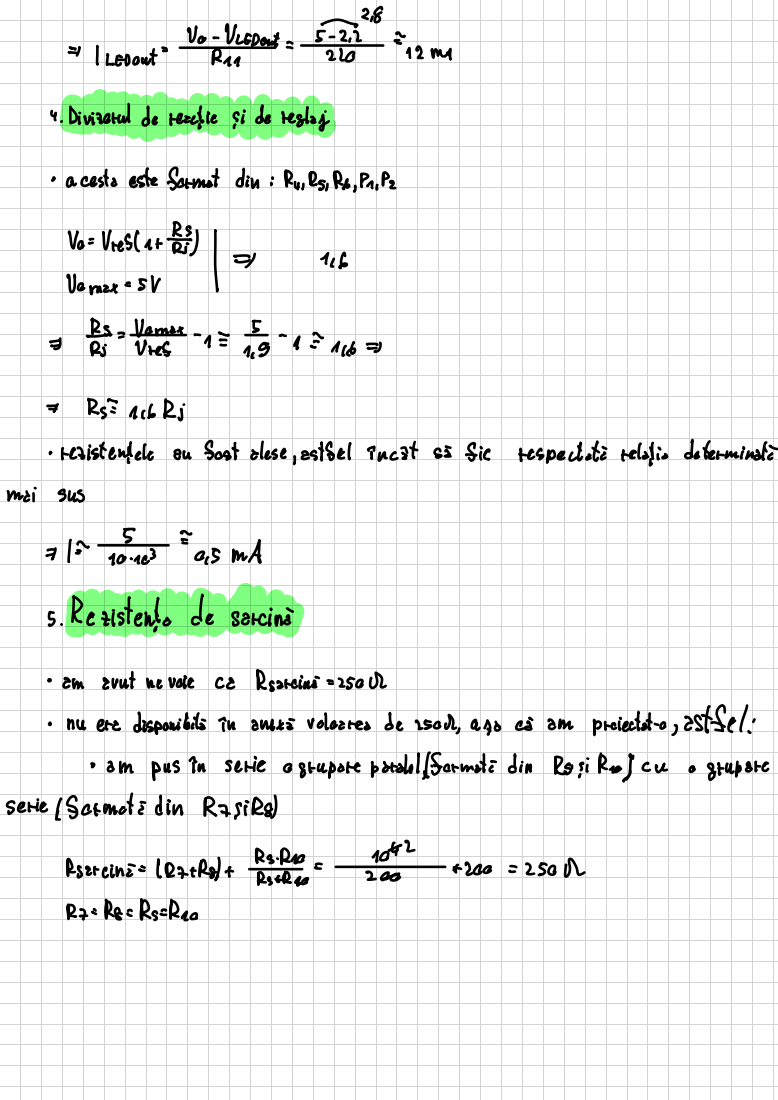
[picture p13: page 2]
ILEDOut =; Divizerul de; teatie; teglaj; acesta; este; format; din : Ry, Rs, Rs,; Vo = Uref(n+; Vomzx = 5V; = VemVtxf たg; rezistentele; an fast; zese; astfel; inct; fie; respectati; telatio; determinati; mai; sus; Fas; Resistene; sarcina; zuut; nevoie; Rsarcini =; nu era; disponibila; anita voloated; ala; proiectatio ,; atfel:; pus; serie; egtupate parall,Formati; din; EssiRof cu a stupate; Serie /Setmetidin; RasiRs); Rszrcini =; 250N RstR10; Rg = Rs=Rea

6. Resistentele | din | circuitul | de | protectio | la | suptecurent

rezistent ele : Res,

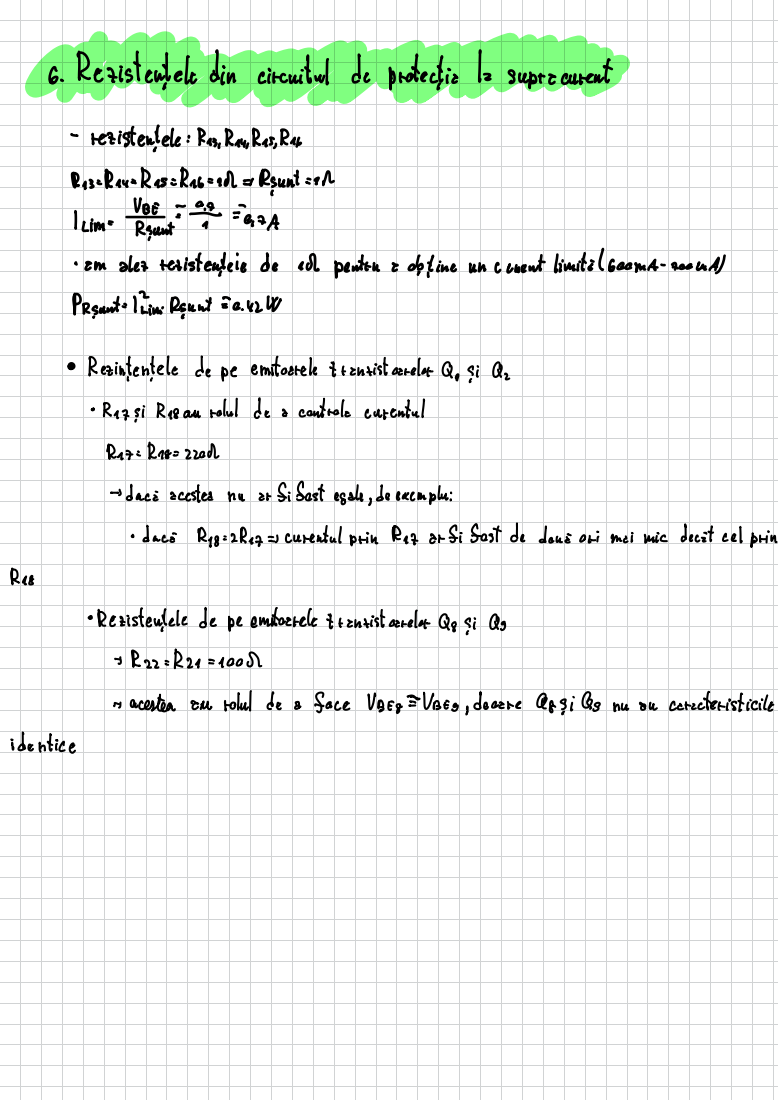
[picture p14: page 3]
Rey,; Res,; Res; Bey = Res:Reb = ed = Asunt = en (; Iim=; alez +existeneie; perten e obtine; un curent limita/beamt-zomAl; Prsunt:; /Mini Runt =c.; Rezintentele; emitacrele tranzistaarelor; Rezsi; Resautoul; controle; curental; Riz:; daca; zested nu; fifest; egale ,; de exemplu:; dace; Ryg :; 2Rez = curental prin Rez; arti fest; de den ori; mai mic; decit cel prin; Rezisteniele; emitaztele tranzistotelar; Assi; acente; zu rolul de; Face; VBigVig ,; decare; Qgsi&s; caracteristicile; identice

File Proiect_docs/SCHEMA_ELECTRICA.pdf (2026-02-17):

0
